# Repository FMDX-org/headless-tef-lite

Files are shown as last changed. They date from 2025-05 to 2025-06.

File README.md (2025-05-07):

# TEF668X Headless Lite USB Tuner

USB radio tuner based on the STM32F072 MCU and TEF668X/V205 RF receiver with digital audio output over USB. This is the lite variant of our [Headless USB tuner](https://github.com/FMDX-org/tef668x-headless-usb-tuner). It is more compact, with a simplified RF input path and only one antenna input for AM/FM.

This design is optimized as a cost-efficient solution tailored for automated PCBA (Printed Circuit Board Assembly) processes.

Copyright (C) 2025 FMDX.org

You may redistribute and modify this source under the terms of the CERN-OHL-W v2 (see LICENSE file).

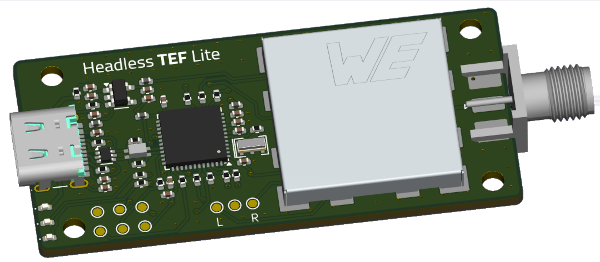
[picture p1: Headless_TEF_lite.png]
Headless TEF Lite


# Credits 

- Konrad Kosmatka - HW & FW architecture and development
- Sjef Verhoeven - HW development
- Marek Kraus - HW & FW prototyping
- Marek Farkaš - testing and integration with FM-DX Webserver
- Przemysław Korpas - HW consultation, reviews
- Sebastian Białkowski - HW consultation, reviews

# Firmware

The firmware is available in a separate repository: [FM-DX-Tuner](https://github.com/kkonradpl/FM-DX-Tuner).

Firmware dependencies:
- Board: STM32 MCU Based Boards ([STM32duino](https://github.com/stm32duino)) - download using board manager
- Library: [TinyUSB](https://github.com/hathach/tinyusb) - install manually to the Arduino libraries

During first firmware flashing, short BOOT to 3.3V, plug the USB cable and flash using Arduino IDE (DFU method). Once the firmware is running, it is not necessary to manually short BOOT pin. See [tef-bootloader](https://github.com/kkonradpl/tef-bootloader).

# Audio output

The baseline version of the tuner supports only digital audio over USB. You can access analog audio via the L and R solder points, but this output is unbuffered. Therefore, you will need to build an additional electronic circuit to achieve proper audio output.

# Important remarks

- TEF6687/V205 (F8705) chip is recommended for the best performance (FMSI, FULL SCAN RDS).
- RF circuits should contain NP0 (C0G) capacitors.
- Only V205 version of TEF668X are supported on this design!
- All capacitors and resistors are 0402.

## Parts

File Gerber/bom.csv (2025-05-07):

Designator | Footprint | Quantity | Value | LCSC Part #
C1 | 0402 | 1 | 4n7
C10, C11, C13, C14, C15, C19, C23, C24, C25, C26, C27, C30, C33 | 0402 | 13 | 100n
C12, C8 | 0402 | 2 | 1p
C16 | 0402 | 1 | 10n
C17, C31, C35 | 0402 | 3 | 12p
C18, C22, C28, C32 | 0402 | 4 | 4u7
C2 | 0402 | 1 | 10p
C20, C29, C9 | 0402 | 3 | 10u
C21, C5 | 0402 | 2 | 1n
C3 | 0402 | 1 | 470p
C34 | 0402 | 1 | 4p7
C4 | 0402 | 1 | 220n
C6 | 0402 | 1 | 1n5
C7 | 0402 | 1 | 1p8
D1 | SOT-363_SC-70-6 | 1 | BAV99S
D2 | D_SOD-323 | 1 | CPDV3V3A-HF
D3 | 0402 | 1 | GREEN
D4 | 0402 | 1 | RED
D5 | 0402 | 1 | BLUE
FB1, FB2, FB3, FB4 | 0402 | 4 | FERRIT
FL1 | USB_Filter_0805 | 1 | ACM2012-202-2P-T002
J1 | 12402012E212A | 1 | 12402012E212A
J2 | SMA_Molex_73251-2120_EdgeMount_Horizontal | 1 | SMA
J3 | 36103205S | 1 | 36903205S
L1 | 0402 | 1 | 820nH
L2 | 0402 | 1 | 3.3uH
L3, L4 | 0402 | 2 | 270nH
L5 | 0402 | 1 | 220nH
R1, R12, R13, R14, R18, R2, R7 | 0402 | 7 | 5K1
R10, R11, R16, R17, R19, R20, R6, R8, R9 | 0402 | 9 | 100R
R15 | 0402 | 1 | 560R
R21, R22, R23 | 0402 | 3 | 2K
R24, R25 | 0402 | 2 | 1k
R3, R4, R5 | 0402 | 3 | 1M
TP1 | TestPoint_Pad_D1.0mm | 1 | R
TP2 | TestPoint_Pad_D1.0mm | 1 | L
TP3, TP4, TP5, TP6, TP7, TP8, TP9 | TestPoint_Pad_D1.0mm | 7 | ~
U1 | QFN-32-1EP_5x5mm_P0.5mm_EP3.3x3.3mm_ThermalVias | 1 | TEF6687HN/V205 (F8705)
U2 | SOT-666 | 1 | USBLC6-2P6
U3 | VQFN-48-1EP_7x7mm_P0.5mm_EP4.1x4.1mm_ThermalVias | 1 | STM32F072CBU6
U4 | SOT-23-5 | 1 | TPS7A2033PDBVR
Y1 | Crystal_SMD_3225-4Pin_3.2x2.5mm | 1 | 55.46667 MHz
Y2 | Resonator_SMD_Murata_CSTxExxV-3Pin_3.0x1.1mm | 1 | 8 MHz

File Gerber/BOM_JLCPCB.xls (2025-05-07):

Comment | Designator | Footprint | JLCPCB Part #
STM32F072CBU6 | U3 | VQFN-48-1EP_7x7mm_P0.5mm_EP4.1x4.1mm_ThermalVias | C92504
RED | D4 | 0402 | C434445
4p7 | C34 | 0402 | C1569
100R | R10,R11,R16,R17,R19,R20,R6,R8,R9 | 0402 | C25076
USBLC6-2P6 | U2 | SOT-666 | C2827693
CPDV3V3A-HF | D2 | D_SOD-323 | C2594895
270nH | L3,L4 | 0402 | C49501
1p | C12,C8 | 0402 | C1550
560R | R15 | 0402 | C163460
BAV99S | D1 | SOT-363_SC-70-6 | C20416655
1n5 | C6 | 0402 | C281752
ACM2012-202-2P-T002 | FL1 | USB_Filter_0805 | C404378
TPS7A2033PDBVR | U4 | SOT-23-5 | C2862740
10p | C2 | 0402 | C32949
4u7 | C18,C22,C28,C32 | 0402 | C23733
470p | C3 | 0402 | C1537
10u | C20,C29,C9 | 0402 | C15525
1p8 | C7 | 0402 | C1553
12p | C17,C31,C35 | 0402 | C1547
220n | C4 | 0402 | C16772
1k | R24,R25 | 0402 | C11702
3.3uH | L2 | 0402 | C84474
220nH | L5 | 0402 | C18834
100n | C10,C11,C13,C14,C15,C19,C23,C24,C25,C26,C27,C30,C33 | 0402 | C1525
5K1 | R1,R12,R13,R14,R18,R2,R7 | 0402 | C25905
2K | R21,R22,R23 | 0402 | C4109
4n7 | C1 | 0402 | C1538
GREEN | D3 | 0402 | C434446
1M | R3,R4,R5 | 0402 | C26083
BLUE | D5 | 0402 | C434447
820nH | L1 | 0402 | C316408
8MHz | Y2 | Resonator_SMD_Murata_CSTxExxV-3Pin_3.0x1.1mm | C341525
12402012E212A | J1 | 12402012E212A | C5150972
1n | C21,C5 | 0402 | C1523
55.46667MHz | Y1 | Crystal_SMD_3225-4Pin_3.2x2.5mm | C312425
10n | C16 | 0402 | C15195
FERRIT | FB1,FB2,FB3,FB4 | 0402 | C14182

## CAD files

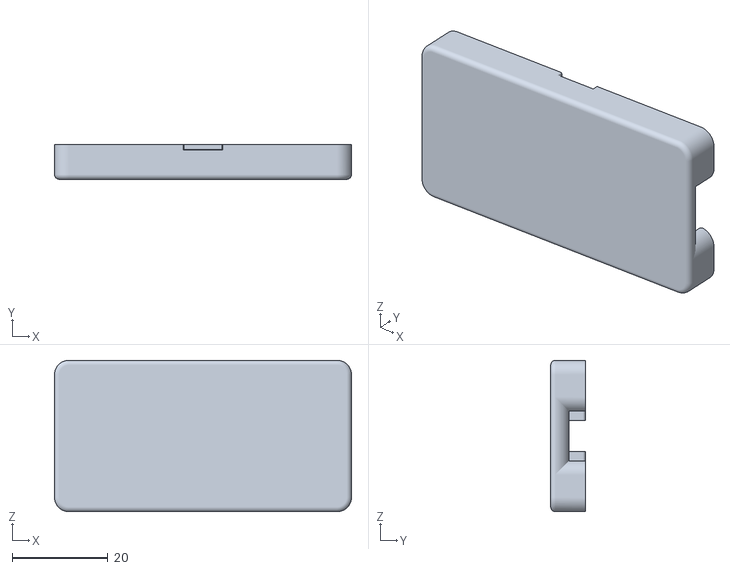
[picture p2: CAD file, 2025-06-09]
3d case/tef_lite_click_bottom.stl
62.0 x 7.23 x 31.6

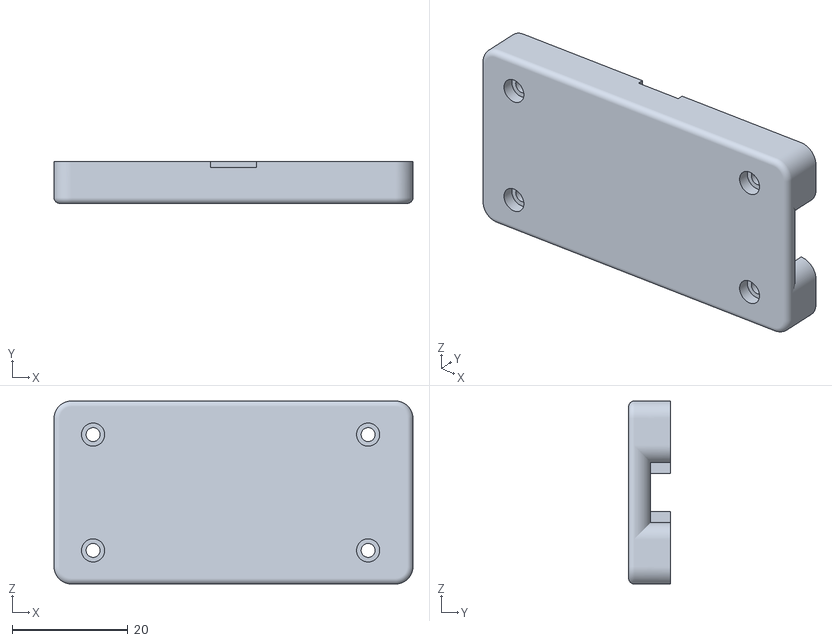
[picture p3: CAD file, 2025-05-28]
3d case/tef_lite_screw_bottom.stl
62.0 x 7.23 x 31.6

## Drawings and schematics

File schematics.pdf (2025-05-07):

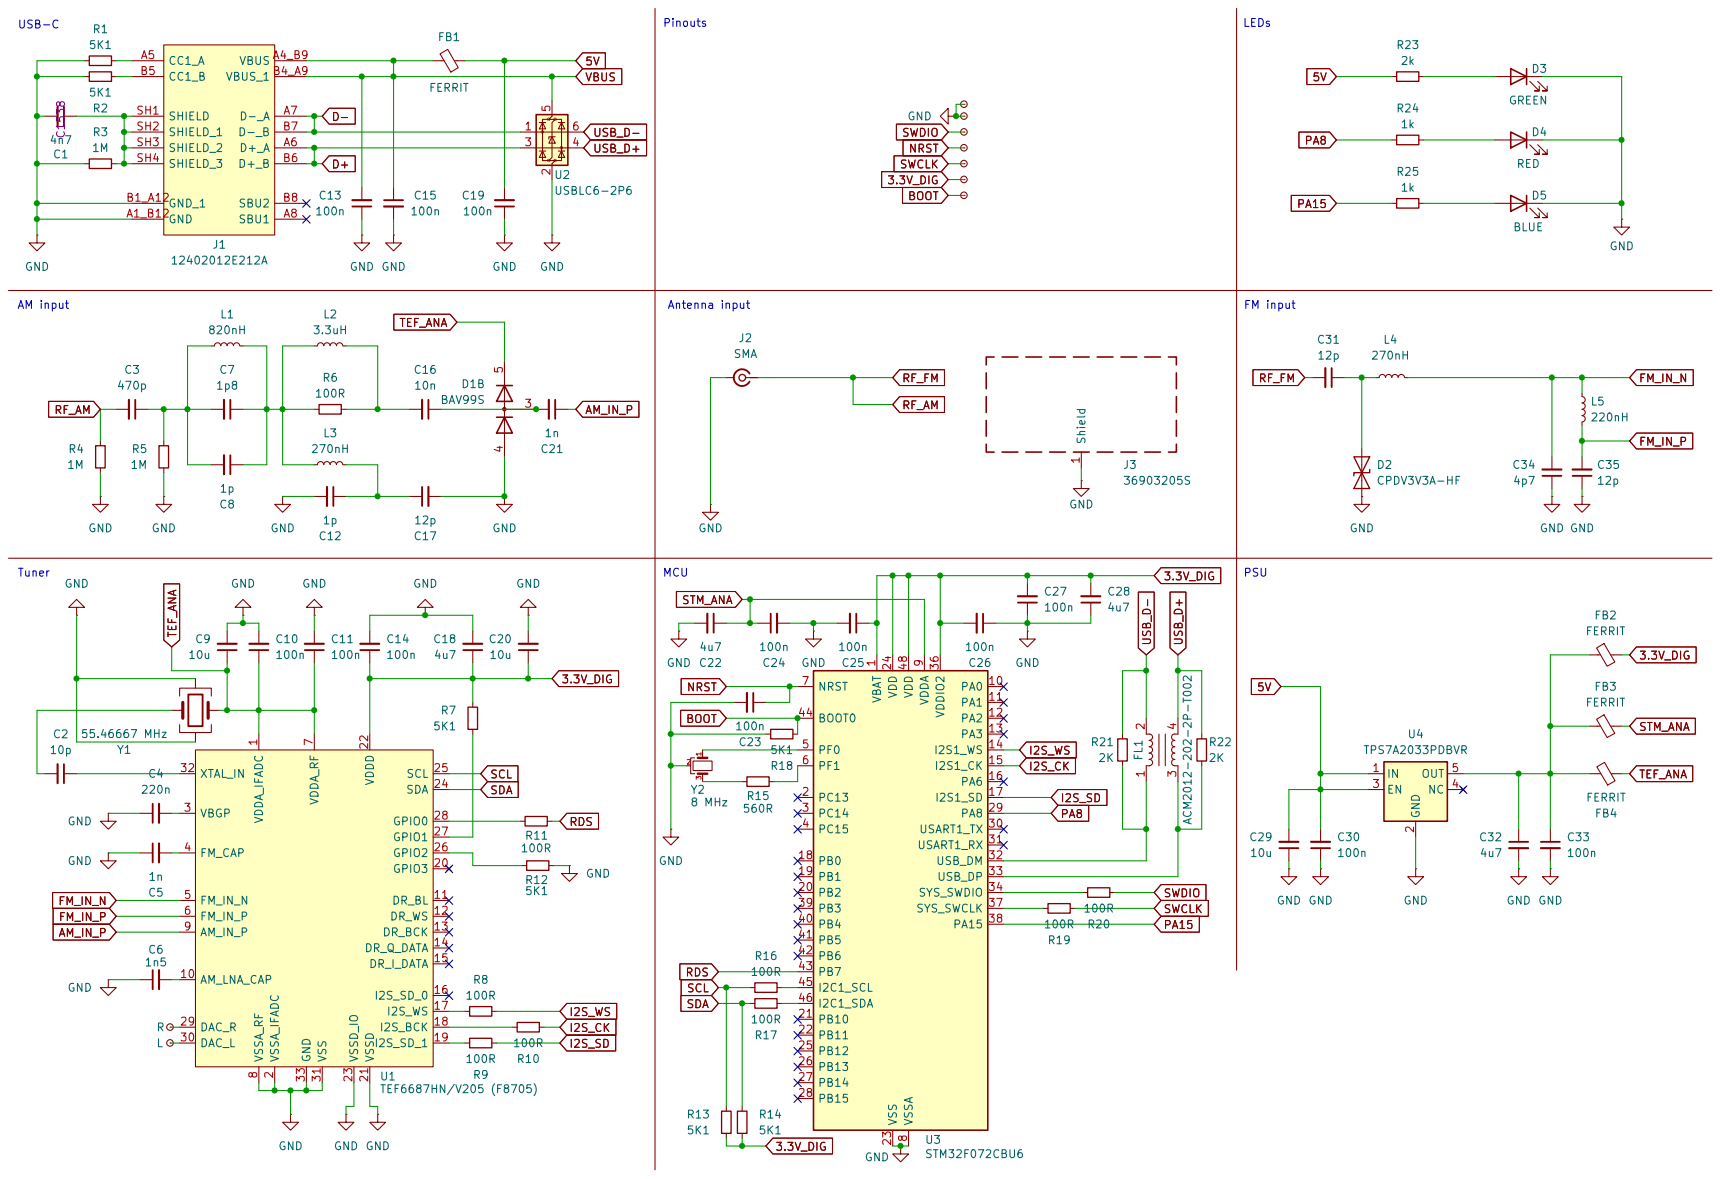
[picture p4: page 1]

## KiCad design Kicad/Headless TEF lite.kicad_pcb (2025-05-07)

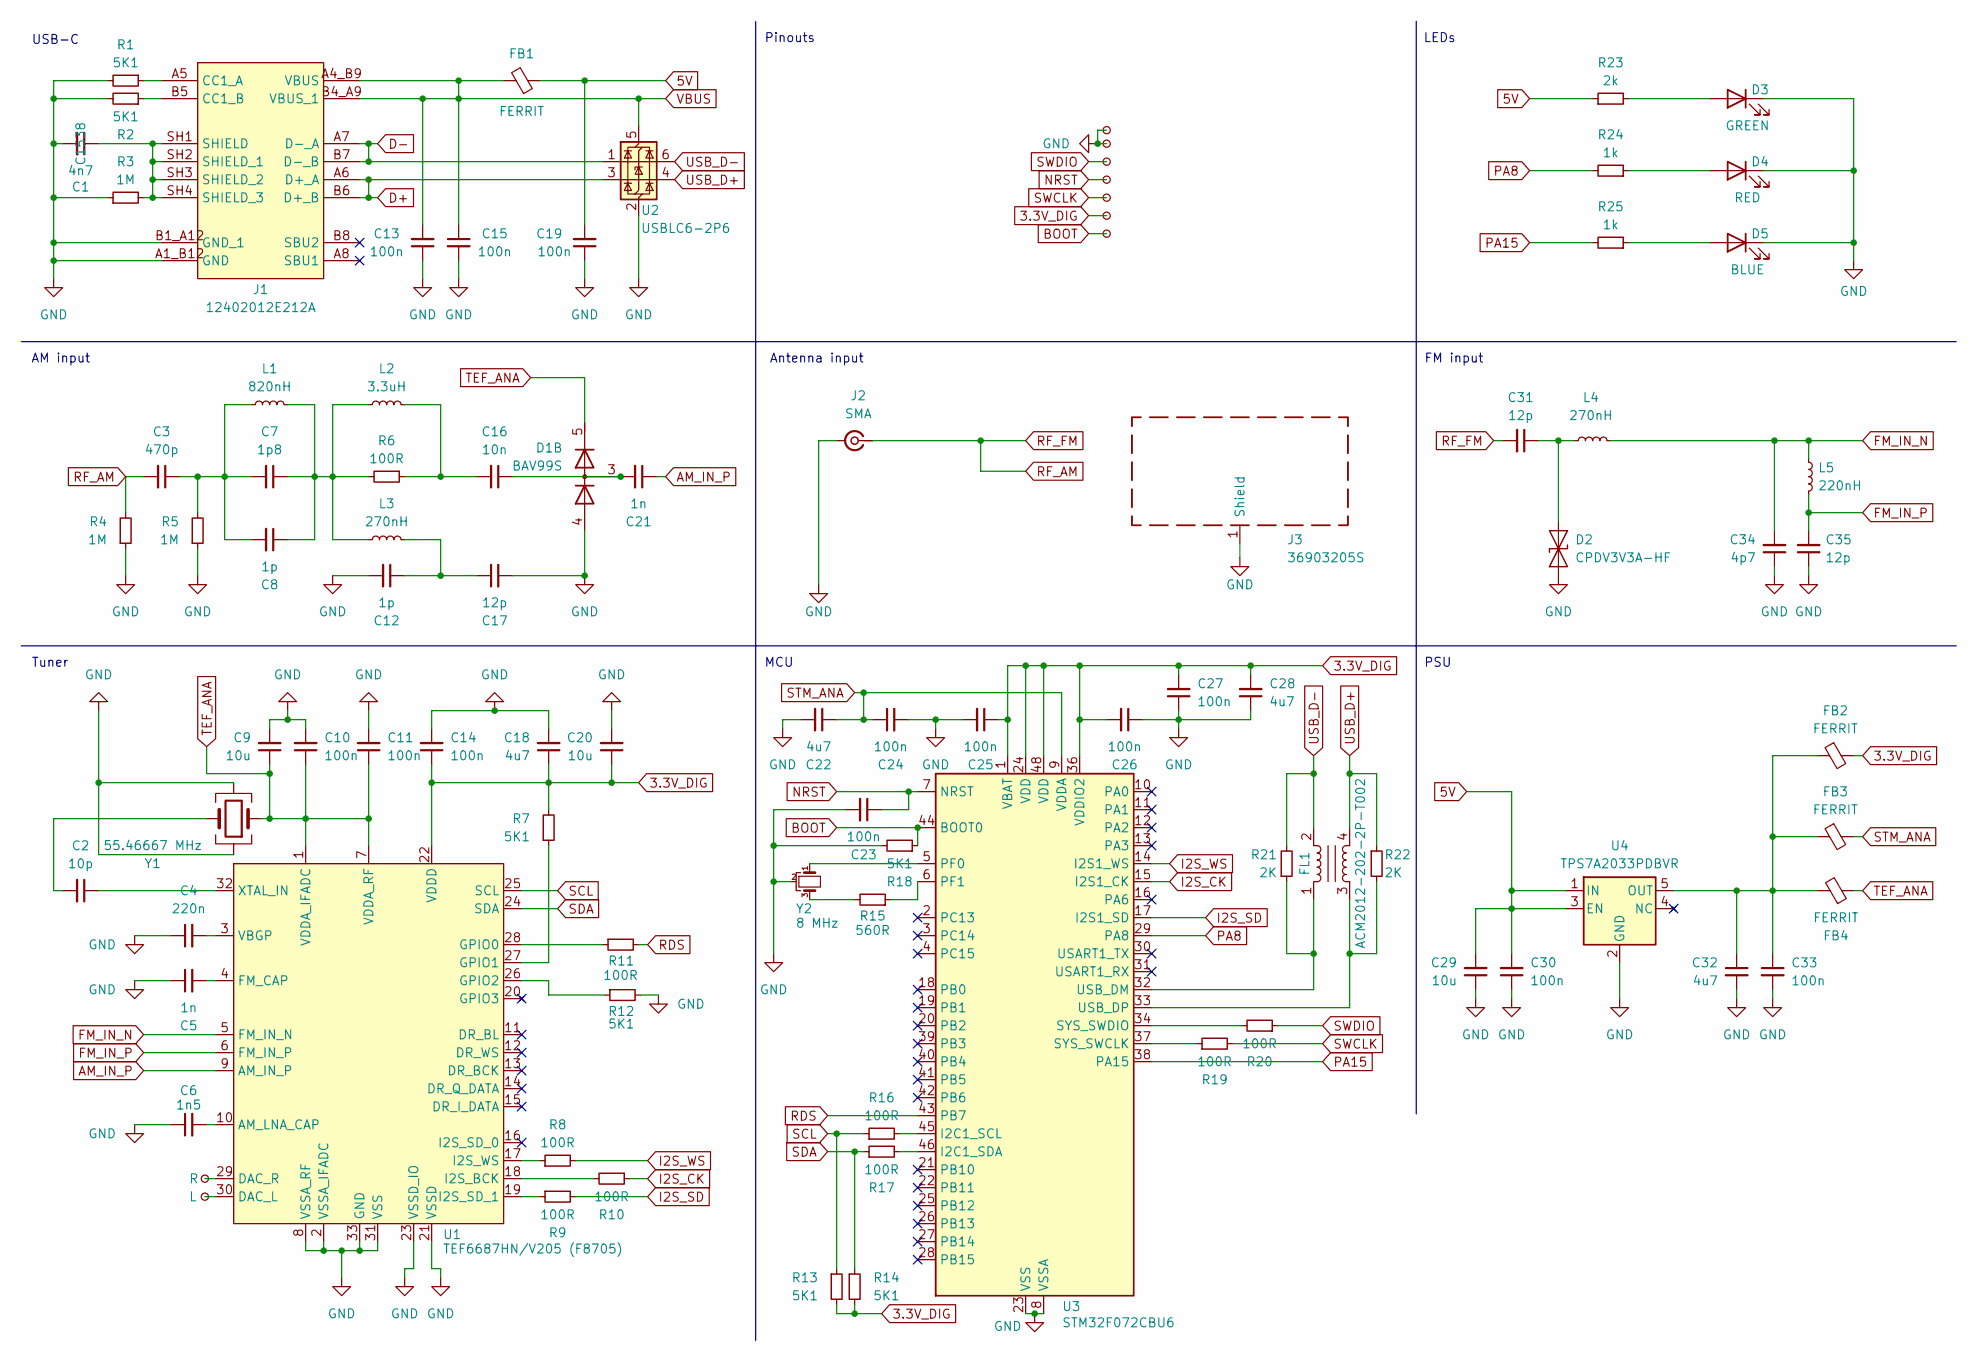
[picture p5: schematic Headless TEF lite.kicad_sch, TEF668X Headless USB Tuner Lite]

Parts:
C1: 4n7; C_0402_1005Metric
C2: 10p; C_0402_1005Metric
C3: 470p; C_0402_1005Metric
C4: 220n; C_0402_1005Metric
C5, C21: 1n; C_0402_1005Metric
C6: 1n5; C_0402_1005Metric
C7: 1p8; C_0402_1005Metric
C8, C12: 1p; C_0402_1005Metric
C9, C20, C29: 10u; C_0402_1005Metric
C10, C11, C13, C14, C15, C19, C23, C24, C25, C26, C27, C30, C33: 100n; C_0402_1005Metric
C16: 10n; C_0402_1005Metric
C17, C31, C35: 12p; C_0402_1005Metric
C18, C22, C28, C32: 4u7; C_0402_1005Metric
C34: 4p7; C_0402_1005Metric
D1: BAV99S; SOT-363_SC-70-6
D2: CPDV3V3A-HF; D_SOD-323
D3: GREEN; LED_0402_1005Metric
D4: RED; LED_0402_1005Metric
D5: BLUE; LED_0402_1005Metric
FB1, FB2, FB3, FB4: FERRIT; L_0402_1005Metric
FL1: ACM2012-202-2P-T002; USB_Filter_0805
J1: 12402012E212A
J2: SMA; SMA_Molex_73251-2120_EdgeMount_Horizontal
J3: 36903205S; 36103205S
L1: 820nH; L_0402_1005Metric
L2: 3.3uH; L_0402_1005Metric
L3, L4: 270nH; L_0402_1005Metric
L5: 220nH; L_0402_1005Metric
R1, R2, R7, R12, R13, R14, R18: 5K1; R_0402_1005Metric
R3, R4, R5: 1M; R_0402_1005Metric
R6, R8, R9, R10, R11, R16, R17, R19, R20: 100R; R_0402_1005Metric
R15: 560R; R_0402_1005Metric
R21, R22: 2K; R_0402_1005Metric
R23: 2k; R_0402_1005Metric
R24, R25: 1k; R_0402_1005Metric
TP1: R; TestPoint_Pad_D1.0mm
TP2: L; TestPoint_Pad_D1.0mm
TP3, TP4, TP5, TP6, TP7, TP8, TP9: TestPoint_Pad_D1.0mm
U1: TEF6687HN/V205 (F8705); QFN-32-1EP_5x5mm_P0.5mm_EP3.3x3.3mm_ThermalVias
U2: USBLC6-2P6; SOT-666
U3: STM32F072CBU6; VQFN-48-1EP_7x7mm_P0.5mm_EP4.1x4.1mm_ThermalVias
U4: TPS7A2033PDBVR; SOT-23-5
Y1: 55.46667 MHz; Crystal_SMD_3225-4Pin_3.2x2.5mm
Y2: 8 MHz; Resonator_SMD_Murata_CSTxExxV-3Pin_3.0x1.1mm

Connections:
3.3V_DIG: C14.1, C18.1, C20.1, C25.1, C26.2, C27.2, C28.2, FB2.2, R7.2, R13.2, R14.2, TP8.1, U1.22 (VDDD), U3.1 (VBAT), U3.24 (VDD), U3.36 (VDDIO2), U3.48 (VDD)
5V: C19.2, C29.2, C30.2, FB1.1, R23.1, U4.1 (IN), U4.3 (EN)
AM_IN_P: C21.1, U1.9 (AM_IN_P)
BOOT: R18.1, TP9.1, U3.44 (BOOT0)
D+: J1.A6 (D+_A), J1.B6 (D+_B), U2.3 (I/O2)
D-: J1.A7 (D-_A), J1.B7 (D-_B), U2.1 (I/O1)
FM_IN_N: C34.2, L4.2, L5.1, U1.5 (FM_IN_N)
FM_IN_P: C35.2, L5.2, U1.6 (FM_IN_P)
GND: C1.2, C4.1, C5.1, C6.1, C9.2, C10.2, C11.2, C12.2, C13.1, C14.2, C15.2, C17.2, C18.2, C19.1, C20.2, C22.2, C23.2, C24.2, C25.2, C26.1, C27.1, C28.1, C29.1, C30.1, C32.2, C33.2, C34.1, C35.1, D1.4 (A3), D2.2 (A2), D3.1 (K), D4.1 (K), D5.1 (K), J1.A1_B12 (GND), J1.B1_A12 (GND_1), J2.2 (Ext), J3.1 (Shield), R1.2, R2.2, R3.1, R4.1, R5.1, R12.2, R18.2, TP3.1, TP4.1, U1.2 (VSSA_IFADC), U1.8 (VSSA_RF), U1.21 (VSSD), U1.23 (VSSD_IO), U1.31 (VSS), U1.33 (GND), U2.2 (GND), U3.8 (VSSA), U3.23 (VSS), U3.35 (VSS), U3.47 (VSS), U3.49 (GND), U4.2 (GND), Y1.2, Y1.4, Y2.2
I2S_CK: R10.1, U3.15 (I2S1_CK)
I2S_SD: R9.2, U3.17 (I2S1_SD)
I2S_WS: R8.2, U3.14 (I2S1_WS)
NRST: C23.1, TP6.1, U3.7 (NRST)
unnamed: C2.2, Y1.3
unnamed: C3.1, C7.2, C8.2, L1.1, R5.2
unnamed: C7.1, C8.1, L1.2, L2.1, L3.1, R6.2
unnamed: C12.1, C17.1, L3.2
unnamed: C16.2, L2.2, R6.1
unnamed: C16.1, C21.2, D1.3 (K1A2)
unnamed: C31.1, D2.1 (A1), L4.1
unnamed: D3.2 (A), R23.2
unnamed: D4.2 (A), R24.1
unnamed: D5.2 (A), R25.1
unnamed: J1.A5 (CC1_A), R1.1
unnamed: J1.B5 (CC1_B), R2.1
unnamed: C1.1, J1.SH1 (SHIELD), J1.SH2 (SHIELD_1), J1.SH3 (SHIELD_2), J1.SH4 (SHIELD_3), R3.2
unnamed: R15.2, Y2.3
unnamed: C6.2, U1.10 (AM_LNA_CAP)
unnamed: TP2.1, U1.30 (DAC_L)
unnamed: TP1.1, U1.29 (DAC_R)
unnamed: C5.2, U1.4 (FM_CAP)
unnamed: R11.1, U1.28 (GPIO0)
unnamed: R7.1, U1.27 (GPIO1)
unnamed: R12.1, U1.26 (GPIO2)
unnamed: R10.2, U1.18 (I2S_BCK)
unnamed: R9.1, U1.19 (I2S_SD_1)
unnamed: R8.1, U1.17 (I2S_WS)
unnamed: C4.2, U1.3 (VBGP)
unnamed: C2.1, U1.32 (XTAL_IN)
unnamed: FL1.1, R21.1, U3.32 (USB_DM)
unnamed: FL1.3, R22.2, U3.33 (USB_DP)
unnamed: R20.2, U3.34 (SYS_SWDIO)
unnamed: R19.1, U3.37 (SYS_SWCLK)
unnamed: R16.2, U3.45 (I2C1_SCL)
unnamed: R17.2, U3.46 (I2C1_SDA)
unnamed: U3.5 (PF0), Y2.1
unnamed: R15.1, U3.6 (PF1)
unnamed: C32.1, C33.1, FB2.1, FB3.1, FB4.2, U4.5 (OUT)
PA8: R24.2, U3.29 (PA8)
PA15: R25.2, U3.38 (PA15)
RDS: R11.2, U3.43 (PB7)
RF_AM: C3.2, C31.2, J2.1 (In), R4.2
SCL: R13.1, R16.1, U1.25 (SCL)
SDA: R14.1, R17.1, U1.24 (SDA)
STM_ANA: C22.1, C24.1, FB3.2, U3.9 (VDDA)
SWCLK: R19.2, TP7.1
SWDIO: R20.1, TP5.1
TEF_ANA: C9.1, C10.1, C11.1, D1.5 (K4), FB4.1, U1.1 (VDDA_IFADC), U1.7 (VDDA_RF), Y1.1
USB_D+: FL1.4, R22.1, U2.4 (I/O2)
USB_D-: FL1.2, R21.2, U2.6 (I/O1)
VBUS: C13.2, C15.1, FB1.2, J1.A4_B9 (VBUS), J1.B4_A9 (VBUS_1), U2.5 (VBUS)

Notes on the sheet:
PSU
Pinouts
AM input
Antenna input
MCU
Tuner
USB-C
FM input
LEDs

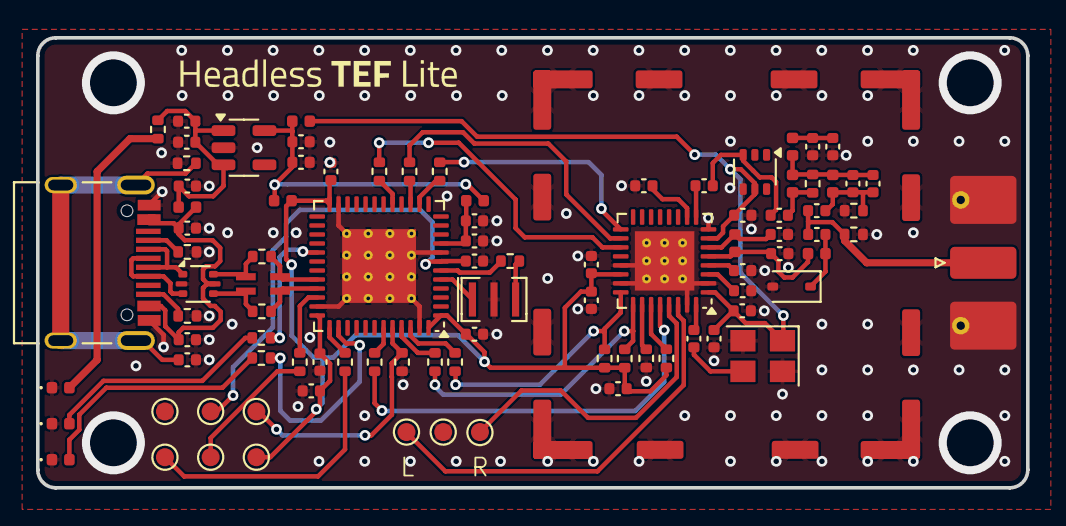
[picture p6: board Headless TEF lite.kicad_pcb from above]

Board: 2 copper layers, 55.0 x 25.0 mm, 93 parts (0 on the bottom side), 61 nets.

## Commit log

2025-05-07 File upload
    [BOM_JLCPCB.xls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]
2025-05-07 Upload schematics
2025-05-28 3d case
    [tef_lite_bottom.stl, tef_lite_top.stl]
2025-06-09 Update STL
    [tef_lite_bottom.stl, tef_lite_click_bottom.stl, tef_lite_screw_bottom.stl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]
